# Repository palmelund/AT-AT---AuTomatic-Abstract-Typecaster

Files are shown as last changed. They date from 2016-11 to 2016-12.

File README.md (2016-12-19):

# AT-AT - AuTomatic Abstract Typecaster

The AT-AT is a sorting machine running on an embedded system and built in lego. The system combines a real-time system running on an Arduino Mega and Machine Intelligence running on an assisting computer.

The machine operates better under the tunes of the Imperial March.

## 5th semester project
This project was made as part of fifth semester of the bachelor in Software Engineering at Aalborg University where the project theme was Embedded software.

## Project structure
The project has the following overall structure to help organising files and source code.

* BmpSort
  * This is the computer side part of the project, that handles communication with the Kinect used as a camera, and makes shape recognition on the resulting image.
  * This part of the project is written in C#. Uses WPF for UI so a windows PC is needed right now.
* arduino
  * This is where all the source code for the Arduino is located, including libraries, API and the souce code
  * Written in C with a little bit of C++. Has full build script for Linux, but more manual work is needed if building on Windows.
* prototype
  * This is where the code for prototypes that was developed early in the project are located
  * This part is programmed in NXT-OSEK using C, LeJOS using Java and on the Arduino using C.
  * This code haven't been touched for a long time, and prototype 4 may not compile due to changes in the API.
* schematics
  * This is where schematics for the construction are located. There are currently two.
  * A wire schematic showing how the hardware is wired up. This can be opened using Fritzinf.
  * A digital model of the machine. This can be opened using LEGO Digital Designer.
  * A fault tree conducted from a fault tree analysis.
* test
  * This is where the code for unit testing, component testing and worst case execution time are located
  
## The Name
The machine was nameless for most of the project, but after every other student told us it looked like an AT-AT we finally gave in, named it AT-AT and printed a paper model of an AT-AT and taped onto it.
  
The name AuTomatic Abstract Typecaster was chosen because it represents what the project is:
* AuTomatic: The machine can operate on its own after it is started, only needing help to fill the feeder and empty the separation unit. These are both components that could also be automated away.
* Abstract: The machine itself can not be used in the industry, but it has many ideas that can be inherited and implemented by other machines to be used in practice.
* Typecaster: Since it is unknown what enters the machine, all is seen as objetcs. By passing though the machine it is being recognised and passed on as a shape, and in case of being a circle, it also has a color propery assigned to it.

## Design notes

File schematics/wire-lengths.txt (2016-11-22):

--- Red ---
++ 1  5v -> board+1                = red 12 cm
++ 6  board+1 -> board             = red 3 cm
++ 1  board+1 -> board+2           = red 8 cm
++ 1  board+2 -> ultra sound board = red 14 + 16 cm
++ 1  board+2 -> color sensor      = red 23 + 16 cm
TODO: Driver

--- Blue ---
++ 1  GND -> board-1               = blue 12 cm
++ 4  board-1 -> board             = blue 3 cm
++ 1  board-1 -> board-2           = blue 8 cm
++ 1  board-2 -> ultra sound board = blue 14 + 16 cm
++ 1  board-2 -> color sensor      = blue 23 + 16 cm
TODO: Driver

--- Yellow ---
++ 1  Pin 29 -> Transistor(Right)   = yellow 8 cm
++ 1  Pin 27 -> Transistor(Left)    = yellow 5 cm
++ 1  Pin 31 -> ultra sound board   = yellow 19 + 16 cm
TODO: Driver

--- Green ---
++ 1  Pin 53 -> ultra sound board   = green 19 + 16 cm
++ 1  Pin 51 -> Terminal(Left)      = green 10 cm

--- White ---
++ 1  Pin 3 -> Terminal(Left)       = white 11 cm
++ 1  Pin 2 -> Terminal(Middle)     = white 11 cm
++ 1  Pin 18 -> Terminal(Right)     = white 13 cm

--- Browm ---
++ 2 Pin 20/21 -> Color sensor      = brown 28 + 16 cm
TODO: Driver

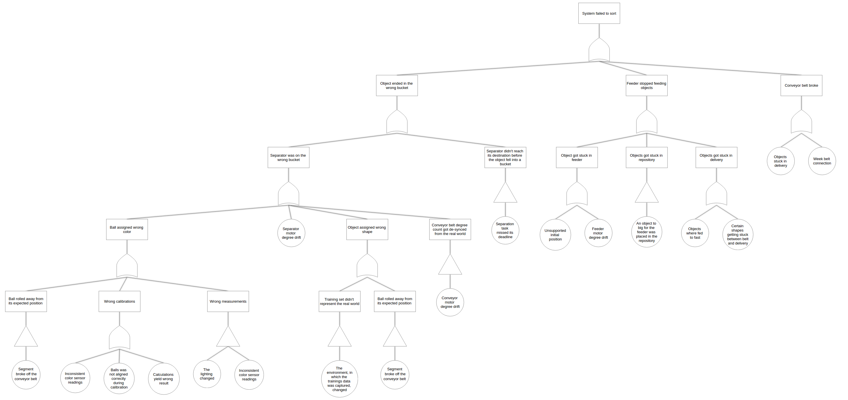
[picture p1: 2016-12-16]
schematics/FaultTreeV4.png

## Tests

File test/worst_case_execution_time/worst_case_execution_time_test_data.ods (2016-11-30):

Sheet: task_check_first_segment
0 | & | 952 | & | 20 | & | 928 | & | 40 | & | 932 | & | 60 | & | 928 | & | 80 | & | 928 | \\ | \hline
1 | & | 948 | & | 21 | & | 928 | & | 41 | & | 928 | & | 61 | & | 928 | & | 81 | & | 952 | \\ | \hline
2 | & | 936 | & | 22 | & | 948 | & | 42 | & | 904 | & | 62 | & | 932 | & | 82 | & | 952 | \\ | \hline
3 | & | 928 | & | 23 | & | 928 | & | 43 | & | 928 | & | 63 | & | 932 | & | 83 | & | 952 | \\ | \hline
4 | & | 956 | & | 24 | & | 932 | & | 44 | & | 928 | & | 64 | & | 928 | & | 84 | & | 952 | \\ | \hline
5 | & | 952 | & | 25 | & | 900 | & | 45 | & | 928 | & | 65 | & | 876 | & | 85 | & | 952 | \\ | \hline
6 | & | 928 | & | 26 | & | 928 | & | 46 | & | 900 | & | 66 | & | 852 | & | 86 | & | 928 | \\ | \hline
7 | & | 928 | & | 27 | & | 928 | & | 47 | & | 956 | & | 67 | & | 952 | & | 87 | & | 928 | \\ | \hline
8 | & | 904 | & | 28 | & | 936 | & | 48 | & | 956 | & | 68 | & | 952 | & | 88 | & | 932 | \\ | \hline
9 | & | 928 | & | 29 | & | 928 | & | 49 | & | 928 | & | 69 | & | 980 | & | 89 | & | 932 | \\ | \hline
10 | & | 928 | & | 30 | & | 952 | & | 50 | & | 928 | & | 70 | & | 952 | & | 90 | & | 952 | \\ | \hline
11 | & | 924 | & | 31 | & | 952 | & | 51 | & | 900 | & | 71 | & | 928 | & | 91 | & | 956 | \\ | \hline
12 | & | 928 | & | 32 | & | 932 | & | 52 | & | 900 | & | 72 | & | 876 | & | 92 | & | 928 | \\ | \hline
13 | & | 952 | & | 33 | & | 924 | & | 53 | & | 928 | & | 73 | & | 924 | & | 93 | & | 932 | \\ | \hline
14 | & | 932 | & | 34 | & | 904 | & | 54 | & | 928 | & | 74 | & | 952 | & | 94 | & | 928 | \\ | \hline
15 | & | 928 | & | 35 | & | 904 | & | 55 | & | 932 | & | 75 | & | 952 | & | 95 | & | 928 | \\ | \hline
16 | & | 932 | & | 36 | & | 928 | & | 56 | & | 948 | & | 76 | & | 928 | & | 96 | & | 932 | \\ | \hline
17 | & | 928 | & | 37 | & | 932 | & | 57 | & | 928 | & | 77 | & | 956 | & | 97 | & | 928 | \\ | \hline
18 | & | 928 | & | 38 | & | 932 | & | 58 | & | 948 | & | 78 | & | 928 | & | 98 | & | 928 | \\ | \hline
19 | & | 932 | & | 39 | & | 960 | & | 59 | & | 932 | & | 79 | & | 928 | & | 99 | & | 952 | \\ | \hline
0 | & | 952 | \\ | \hline
1 | & | 948 | \\ | \hline
2 | & | 936 | \\ | \hline
3 | & | 928 | \\ | \hline
4 | & | 956 | \\ | \hline
5 | & | 952 | \\ | \hline
6 | & | 928 | \\ | \hline
7 | & | 928 | \\ | \hline
8 | & | 904 | \\ | \hline
9 | & | 928 | \\ | \hline
10 | & | 928 | \\ | \hline
11 | & | 924 | \\ | \hline
12 | & | 928 | \\ | \hline
13 | & | 952 | \\ | \hline
14 | & | 932 | \\ | \hline
15 | & | 928 | \\ | \hline
16 | & | 932 | \\ | \hline
17 | & | 928 | \\ | \hline
18 | & | 928 | \\ | \hline
19 | & | 932 | \\ | \hline
20 | & | 928 | \\ | \hline
21 | & | 928 | \\ | \hline
22 | & | 948 | \\ | \hline
23 | & | 928 | \\ | \hline
24 | & | 932 | \\ | \hline
25 | & | 900 | \\ | \hline
26 | & | 928 | \\ | \hline
27 | & | 928 | \\ | \hline
28 | & | 936 | \\ | \hline
29 | & | 928 | \\ | \hline
30 | & | 952 | \\ | \hline
31 | & | 952 | \\ | \hline
32 | & | 932 | \\ | \hline
33 | & | 924 | \\ | \hline
34 | & | 904 | \\ | \hline
35 | & | 904 | \\ | \hline
36 | & | 928 | \\ | \hline
37 | & | 932 | \\ | \hline
38 | & | 932 | \\ | \hline
39 | & | 960 | \\ | \hline
40 | & | 932 | \\ | \hline
41 | & | 928 | \\ | \hline
42 | & | 904 | \\ | \hline
43 | & | 928 | \\ | \hline
44 | & | 928 | \\ | \hline
45 | & | 928 | \\ | \hline
46 | & | 900 | \\ | \hline
47 | & | 956 | \\ | \hline
48 | & | 956 | \\ | \hline
49 | & | 928 | \\ | \hline
50 | & | 928 | \\ | \hline
51 | & | 900 | \\ | \hline
52 | & | 900 | \\ | \hline
53 | & | 928 | \\ | \hline
54 | & | 928 | \\ | \hline
55 | & | 932 | \\ | \hline
56 | & | 948 | \\ | \hline
57 | & | 928 | \\ | \hline
58 | & | 948 | \\ | \hline
59 | & | 932 | \\ | \hline
60 | & | 928 | \\ | \hline
61 | & | 928 | \\ | \hline
62 | & | 932 | \\ | \hline
63 | & | 932 | \\ | \hline
64 | & | 928 | \\ | \hline
65 | & | 876 | \\ | \hline
66 | & | 852 | \\ | \hline
67 | & | 952 | \\ | \hline
68 | & | 952 | \\ | \hline
69 | & | 980 | \\ | \hline
70 | & | 952 | \\ | \hline
71 | & | 928 | \\ | \hline
72 | & | 876 | \\ | \hline
73 | & | 924 | \\ | \hline
74 | & | 952 | \\ | \hline
75 | & | 952 | \\ | \hline
76 | & | 928 | \\ | \hline
77 | & | 956 | \\ | \hline
78 | & | 928 | \\ | \hline
79 | & | 928 | \\ | \hline
80 | & | 928 | \\ | \hline
81 | & | 952 | \\ | \hline
82 | & | 952 | \\ | \hline
83 | & | 952 | \\ | \hline
84 | & | 952 | \\ | \hline
85 | & | 952 | \\ | \hline
86 | & | 928 | \\ | \hline
87 | & | 928 | \\ | \hline
88 | & | 932 | \\ | \hline
89 | & | 932 | \\ | \hline
90 | & | 952 | \\ | \hline
91 | & | 956 | \\ | \hline
92 | & | 928 | \\ | \hline
93 | & | 932 | \\ | \hline
94 | & | 928 | \\ | \hline
95 | & | 928 | \\ | \hline
96 | & | 932 | \\ | \hline
97 | & | 928 | \\ | \hline
98 | & | 928 | \\ | \hline
99 | & | 952 | \\ | \hline
 | Best | 852
 | Aveage | 931.92
 | Worst | 980

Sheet: task_send_take_picture
0 | & | 40 | & | 20 | & | 40 | & | 40 | & | 40 | & | 60 | & | 40 | & | 80 | & | 36 | \\ | \hline
1 | & | 40 | & | 21 | & | 40 | & | 41 | & | 40 | & | 61 | & | 40 | & | 81 | & | 36 | \\ | \hline
2 | & | 40 | & | 22 | & | 40 | & | 42 | & | 40 | & | 62 | & | 40 | & | 82 | & | 40 | \\ | \hline
3 | & | 40 | & | 23 | & | 40 | & | 43 | & | 48 | & | 63 | & | 40 | & | 83 | & | 36 | \\ | \hline
4 | & | 36 | & | 24 | & | 40 | & | 44 | & | 44 | & | 64 | & | 60 | & | 84 | & | 40 | \\ | \hline
5 | & | 40 | & | 25 | & | 40 | & | 45 | & | 40 | & | 65 | & | 40 | & | 85 | & | 40 | \\ | \hline
6 | & | 40 | & | 26 | & | 40 | & | 46 | & | 40 | & | 66 | & | 36 | & | 86 | & | 36 | \\ | \hline
7 | & | 36 | & | 27 | & | 36 | & | 47 | & | 36 | & | 67 | & | 40 | & | 87 | & | 40 | \\ | \hline
8 | & | 40 | & | 28 | & | 40 | & | 48 | & | 36 | & | 68 | & | 40 | & | 88 | & | 36 | \\ | \hline
9 | & | 40 | & | 29 | & | 40 | & | 49 | & | 40 | & | 69 | & | 44 | & | 89 | & | 40 | \\ | \hline
10 | & | 40 | & | 30 | & | 40 | & | 50 | & | 40 | & | 70 | & | 36 | & | 90 | & | 40 | \\ | \hline
11 | & | 40 | & | 31 | & | 40 | & | 51 | & | 40 | & | 71 | & | 40 | & | 91 | & | 36 | \\ | \hline
12 | & | 36 | & | 32 | & | 36 | & | 52 | & | 40 | & | 72 | & | 40 | & | 92 | & | 40 | \\ | \hline
13 | & | 36 | & | 33 | & | 40 | & | 53 | & | 40 | & | 73 | & | 36 | & | 93 | & | 40 | \\ | \hline
14 | & | 40 | & | 34 | & | 40 | & | 54 | & | 36 | & | 74 | & | 36 | & | 94 | & | 44 | \\ | \hline
15 | & | 40 | & | 35 | & | 40 | & | 55 | & | 40 | & | 75 | & | 40 | & | 95 | & | 40 | \\ | \hline
16 | & | 40 | & | 36 | & | 36 | & | 56 | & | 36 | & | 76 | & | 40 | & | 96 | & | 40 | \\ | \hline
17 | & | 40 | & | 37 | & | 40 | & | 57 | & | 40 | & | 77 | & | 36 | & | 97 | & | 36 | \\ | \hline
18 | & | 40 | & | 38 | & | 36 | & | 58 | & | 36 | & | 78 | & | 40 | & | 98 | & | 40 | \\ | \hline
19 | & | 44 | & | 39 | & | 36 | & | 59 | & | 36 | & | 79 | & | 40 | & | 99 | & | 40 | \\ | \hline
0 | & | 40 | \\ | \hline
1 | & | 40 | \\ | \hline
2 | & | 40 | \\ | \hline
3 | & | 40 | \\ | \hline
4 | & | 36 | \\ | \hline
5 | & | 40 | \\ | \hline
6 | & | 40 | \\ | \hline
7 | & | 36 | \\ | \hline
8 | & | 40 | \\ | \hline
9 | & | 40 | \\ | \hline
10 | & | 40 | \\ | \hline
11 | & | 40 | \\ | \hline
12 | & | 36 | \\ | \hline
13 | & | 36 | \\ | \hline
14 | & | 40 | \\ | \hline
15 | & | 40 | \\ | \hline
16 | & | 40 | \\ | \hline
17 | & | 40 | \\ | \hline
18 | & | 40 | \\ | \hline
19 | & | 44 | \\ | \hline
20 | & | 40 | \\ | \hline
21 | & | 40 | \\ | \hline
22 | & | 40 | \\ | \hline
23 | & | 40 | \\ | \hline
24 | & | 40 | \\ | \hline
25 | & | 40 | \\ | \hline
26 | & | 40 | \\ | \hline
27 | & | 36 | \\ | \hline
28 | & | 40 | \\ | \hline
29 | & | 40 | \\ | \hline
30 | & | 40 | \\ | \hline
31 | & | 40 | \\ | \hline
32 | & | 36 | \\ | \hline
33 | & | 40 | \\ | \hline
34 | & | 40 | \\ | \hline
35 | & | 40 | \\ | \hline
36 | & | 36 | \\ | \hline
37 | & | 40 | \\ | \hline
38 | & | 36 | \\ | \hline
39 | & | 36 | \\ | \hline
40 | & | 40 | \\ | \hline
41 | & | 40 | \\ | \hline
42 | & | 40 | \\ | \hline
43 | & | 48 | \\ | \hline
44 | & | 44 | \\ | \hline
45 | & | 40 | \\ | \hline
46 | & | 40 | \\ | \hline
47 | & | 36 | \\ | \hline
48 | & | 36 | \\ | \hline
49 | & | 40 | \\ | \hline
50 | & | 40 | \\ | \hline
51 | & | 40 | \\ | \hline
52 | & | 40 | \\ | \hline
53 | & | 40 | \\ | \hline
54 | & | 36 | \\ | \hline
55 | & | 40 | \\ | \hline
56 | & | 36 | \\ | \hline
57 | & | 40 | \\ | \hline
58 | & | 36 | \\ | \hline
59 | & | 36 | \\ | \hline
60 | & | 40 | \\ | \hline
61 | & | 40 | \\ | \hline
62 | & | 40 | \\ | \hline
63 | & | 40 | \\ | \hline
64 | & | 60 | \\ | \hline
65 | & | 40 | \\ | \hline
66 | & | 36 | \\ | \hline
67 | & | 40 | \\ | \hline
68 | & | 40 | \\ | \hline
69 | & | 44 | \\ | \hline
70 | & | 36 | \\ | \hline
71 | & | 40 | \\ | \hline
72 | & | 40 | \\ | \hline
73 | & | 36 | \\ | \hline
74 | & | 36 | \\ | \hline
75 | & | 40 | \\ | \hline
76 | & | 40 | \\ | \hline
77 | & | 36 | \\ | \hline
78 | & | 40 | \\ | \hline
79 | & | 40 | \\ | \hline
80 | & | 36 | \\ | \hline
81 | & | 36 | \\ | \hline
82 | & | 40 | \\ | \hline
83 | & | 36 | \\ | \hline
84 | & | 40 | \\ | \hline
85 | & | 40 | \\ | \hline
86 | & | 36 | \\ | \hline
87 | & | 40 | \\ | \hline
88 | & | 36 | \\ | \hline
89 | & | 40 | \\ | \hline
90 | & | 40 | \\ | \hline
91 | & | 36 | \\ | \hline
92 | & | 40 | \\ | \hline
93 | & | 40 | \\ | \hline
94 | & | 44 | \\ | \hline
95 | & | 40 | \\ | \hline
96 | & | 40 | \\ | \hline
97 | & | 36 | \\ | \hline
98 | & | 40 | \\ | \hline
99 | & | 40 | \\ | \hline
 | Best | 36
 | Aveage | 39.36
 | Worst | 60
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

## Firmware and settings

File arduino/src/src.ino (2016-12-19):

#include "src.h"

/* PLAN
 *
 * Startup command interface
 *  * Calibrate colors
 *  * Get color calibrations and measured distance
 *  * Start sorting machine
 *
 * Feed ball
 *  * feed_ball()
 * Ping color and Sound
 *  * Multiple code things
 * Send command
 *  * command_take_picture()
 * Request object
 *  * request_object_info()
 * Move separator
 *  * Multiple code things
 */

SFE_ISL29125 rgb_sensor;
Motor motor_conveyor, motor_feeder;
Advanced_Motor adv_motor_separator;

// 0: RED
// 1: GREEN
// 2: BLUE
// 3: YELLOW
// 4: BACKGROUND
Delta_RGB colors[COLOR_COUNT] = {
    {{941, 1147, 951}, 204},
    {{699, 1154, 978}, 225},
    {{698, 1122, 1134}, 234},
    {{1204, 1699, 1099}, 452}
    //{{708, 1087, 940}, 235}
};

Segment_Queue segment_queue;
int32_t conveyor_target;

// -------------------------------
// Arduino main functions
// -------------------------------
void setup()
{
    // Open serial connection
    Serial.begin(9600);
    while (!Serial)
        ;

    // Initialize color sensor
    rgb_sensor.init();

    DEBUG_PRINTLN("Initializing all components...");

    DEBUG_PRINTLN("- Motors...");
    
    motor_init(&motor_conveyor, 0.20, MOTOR_CONVEYOR_PIN, 
               MOTOR_CONVEYOR_INT_PIN, MOTOR_CONVEYOR_DATA_PIN,
               motor_conveyor_interrupt);
    motor_init(&motor_feeder, 1.0, MOTOR_FEEDER_PIN, 
               MOTOR_FEEDER_INT_PIN, MOTOR_FEEDER_DATA_PIN,
               motor_feeder_interrupt);

    advanced_motor_init(&adv_motor_separator, 1.0, MOTOR_SEPARATOR_PIN1,
                        MOTOR_SEPARATOR_PIN2, MOTOR_SEPARATOR_INT_PIN, MOTOR_SEPARATOR_DATA_PIN,
                        adv_motor_separator_interrupt1);

    DEBUG_PRINTLN("- Color sensor...");
    while (rgb_sensor.readRed() == 0 ||
           rgb_sensor.readGreen() == 0 ||
           rgb_sensor.readBlue() == 0)
        ;
    motor_stop(&motor_conveyor);

    for (;;)
    {
        Message message;
        io_await_message(&message);
        if (message.type == MESSAGE_TYPE_COMMAND &&
            message.command.type == MESSAGE_COMMAND_START)
        {
            break;
        }
    }

    motor_turn(&motor_conveyor);
    advanced_motor_turn_to_degree(&adv_motor_separator, GARBAGE_BUCKET);

#if CALIBRATE_COLORS
    task_calibrate_colors(&conveyor_target, &motor_conveyor, &rgb_sensor,
                          colors);
#endif
}

void loop()
{
    task_check_first_segment(&segment_queue);
    task_determin_color(&rgb_sensor, &segment_queue, colors);
    task_rotate_seperator(&adv_motor_separator, &segment_queue);
    task_feed_ball(&motor_feeder);

    if (motor_get_degrees(&motor_conveyor) >= conveyor_target)
    {
        // This will only happen if a deadline is missed
        ASSERT(false);
    }

    while (motor_get_degrees(&motor_conveyor) < conveyor_target)
    { }
    conveyor_target += SEGMENT_DEGREE_LENGTH;
}

// -------------------------------
// Interrupt functions
// -------------------------------
void motor_conveyor_interrupt()
{
    motor_update_degrees(&motor_conveyor);
}

void motor_feeder_interrupt()
{
    motor_update_degrees(&motor_feeder);
}

void adv_motor_separator_interrupt1()
{
    advanced_motor_update_degrees(&adv_motor_separator);
}

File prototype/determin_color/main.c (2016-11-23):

#include <stdio.h>

#define COLORS 8
typedef enum 
{
    RED     = 0,
    GREEN   = 1,
    BLUE    = 2,
    YELLOW  = 3,
    PINK    = 4,
    CYAN    = 5,
    WHITE   = 6,
    BLACK   = 7,
} Color;

short colors[COLORS][3]
{
    { 255,   0,   0 }, // RED
    {   0, 255,   0 }, // GREEN
    {   0,   0, 255 }, // BLUE
    { 255, 255,   0 }, // YELLOW
    { 255,   0, 255 }, // PINK
    {   0, 255, 255 }, // CYAN
    { 255, 255, 255 }, // WHITE
    {   0,   0,   0 }, // BLACK
};

#define ifprint(c, s) case c: printf(#s); break;

void print_color(Color color) 
{
    switch (color) {
        ifprint(RED,    Red);
        ifprint(GREEN,  Green);
        ifprint(BLUE,   Blue);
        ifprint(YELLOW, Yellow);
        ifprint(PINK,   Pink);
        ifprint(CYAN,   Cyan);
        ifprint(WHITE,  White);
        ifprint(BLACK,  Black);
    }
}

int isqrt(int number) 
{
    int res = 0;
    int bit = 1 << 30; // The second-to-top bit is set: 1 << 30 for 32 bits
 
    // "bit" starts at the highest power of four <= the argument.
    while (bit > number)
        bit >>= 2;
        
    while (bit != 0) 
    {
        if (number >= res + bit) 
        {
            number -= res + bit;
            res = (res >> 1) + bit;
        }
        else
        {
            res >>= 1;
        }

        bit >>= 2;
    }
    
    return res;
}

int euclidean_distanceance_3d(short* vec1, short* vec2) 
{
    int res1 = vec1[0] - vec2[0];
    int res2 = vec1[1] - vec2[1];
    int res3 = vec1[2] - vec2[2];

    return isqrt(res1*res1 + res2*res2 + res3*res3);
}

Color determin_color(short* rgb) 
{
    int i, min = 2147483647;
    Color res;

    for (i = 0; i < COLORS; i++) 
    {
        int distance = euclidean_distanceance_3d(colors[i], rgb);
        
        if (distance < min) {
            res = i;
            min = distance;
        }
    }

    return res;
}

#define determin_and_print(name, r, g, b)   \
short name[3] = { r, g, b };                \
printf(#name);                              \
printf(": ");                               \
print_color(determin_color(name));          \
printf("\n");                               

int main() 
{
    calibrate_sensor();
    determin_and_print(redish,    204,   0,   0 );
    determin_and_print(greenish,    0, 153,  51 );
    determin_and_print(blueish,     0,  51, 204 );
    determin_and_print(yellowish, 204, 204,   0 );
    determin_and_print(pinkish,   255,  77, 255 );
    determin_and_print(cyanish,     0, 255, 153 );
    determin_and_print(brownish,  102,  51,   0 );
    determin_and_print(darkgray,   64,  64,  64 );
    determin_and_print(lightgray, 191, 191, 191 );
    return 0;
}

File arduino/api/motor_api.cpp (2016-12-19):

#include "motor_api.h"

/************************
 * Non public functions *
 ************************/
int32_t base_motor_get_degrees(Base_Motor *motor)
{
    int32_t res;

    // Mark reading as true, so no race conditions occur
    motor->reading = true;
    res = motor->degrees;

    // Just to make sure motor->degrees never changes when reading = true
    ASSERT(res == motor->degrees);
    motor->reading = false;

    return res * motor->degree_ratio;
}

void base_motor_init(Base_Motor* motor, float degree_ratio,
                uint8_t interrupt_pin1, uint8_t interrupt_pin2, 
                void (*interrupt_handler)(void))
{
    motor->interrupt_pin1 = interrupt_pin1;
    motor->interrupt_pin2 = interrupt_pin2;
    motor->degree_ratio = degree_ratio;
    motor->buffer = 0;
    motor->degrees = 0;
    motor->reading = false;
    
    pinMode(interrupt_pin1, INPUT_PULLUP);
    pinMode(interrupt_pin2, INPUT_PULLUP);
    attachInterrupt(digitalPinToInterrupt(interrupt_pin1), 
                    interrupt_handler, CHANGE);
}



void base_motor_update_degrees(Base_Motor *motor)
{
    byte pattern = digitalRead(motor->interrupt_pin1);
    pattern |= (digitalRead(motor->interrupt_pin2) << 1);

    // We determin the direction by a pattern formed by the values
    // read from pin1 and pin2
    // LOW = 0, HIGH = 1
    switch (pattern)
    {
    case 0b11:
    case 0b00:
        motor->direction = FORWARD;
        break;
    case 0b10:
    case 0b01:
        motor->direction = BACKWARD;
        break;
    default:
        ASSERT(false);
        break;
    }

    // If degrees are being read, update a buffer instead to avoid race condtions
    if (motor->reading)
    {
        motor->buffer += motor->direction;
    }
    else
    {
        // We need to add and reset the buffer when we are allowed to
        // write to the degrees
        motor->degrees += motor->direction + motor->buffer;
        motor->buffer = 0;
    }
}

/********************
 * Public functions *
 ********************/
void motor_init(Motor *motor, float degree_ratio, uint8_t pin,
                uint8_t interrupt_pin1, uint8_t interrupt_pin2, 
                void (*interrupt_handler)(void))
{
    base_motor_init(&motor->base, degree_ratio, interrupt_pin1, 
                    interrupt_pin2, interrupt_handler);

    motor->pin = pin;
    pinMode(pin, OUTPUT);
}

void advanced_motor_init(Advanced_Motor *motor, float degree_ratio,
                         uint8_t pin1, uint8_t pin2, uint8_t interrupt_pin1,
                         uint8_t interrupt_pin2,
                         void (*interrupt_handler)(void))
{
    base_motor_init(&motor->base, degree_ratio, interrupt_pin1, 
                    interrupt_pin2, interrupt_handler);

    motor->pin1 = pin1;
    motor->pin2 = pin2;

    pinMode(pin1, OUTPUT);
    pinMode(pin2, OUTPUT);
}

bool advanced_motor_turn_to_degree(Advanced_Motor *motor, uint16_t degree)
{
    // Turn to degree should only accept a degree value between
    // 0 and 359 inclusive
    ASSERT(degree < 360);

    int32_t current_pos = advanced_motor_get_degrees(motor);

    // We need to floor, because default casting rounds towards 0, and
    // we always wants it to round down for these calculations to work.
    int32_t turns = floor(current_pos / 360.0);

    // We need to choose two goal, one above and one below our current_pos.
    // These goal needs to be the full number representaion of the degree number
    // that has to be reached.
    int32_t goal2, goal1 = 360 * turns + degree;
    int32_t distance_forward, distance_backward;

    if (goal1 > current_pos)
    {
        goal2 = 360 * (turns - 1) + degree;
        distance_forward = current_pos - goal2;
        distance_backward = goal1 - current_pos;
    }
    else if (goal1 < current_pos)
    {
        goal2 = 360 * (turns + 1) + degree;
        distance_forward = current_pos - goal1;
        distance_backward = goal2 - current_pos;
    }
    // If goal and current_pos are equal, the motor doesn't need to turn, so
    // we just return
    else
    {
        return;
    }

    ASSERT(distance_forward >= 0);
    ASSERT(distance_backward >= 0);

    // Choose which direction to turn based on which distance is shortest
    if (distance_forward < distance_backward)
        return advanced_motor_turn_degrees(motor, distance_forward, FORWARD);
    else
        return advanced_motor_turn_degrees(motor, distance_backward, BACKWARD);
}

bool motor_turn_to_degree(Motor *motor, uint16_t degree)
{
    // Turn to degree should only accept a degree value between
    // 0 and 359 inclusive
    ASSERT(degree < 360);

    int32_t current_pos = motor_get_degrees(motor);
    int32_t turns = (current_pos / 360);
    int32_t goal = 360 * turns + degree;

    // If goal is lower than current_pos, then we need to choose a new goal,
    // 360 degrees bigger
    if (goal < current_pos)
        goal = 360 * (turns + 1) + degree;

    // Turn motor by the distance to the goal
    return motor_turn_degrees(motor, goal - current_pos);
}

bool lesser_than(int32_t value1, int32_t value2)
{
    return value1 < value2;
}

bool greater_than(int32_t value1, int32_t value2)
{
    return value1 > value2;
}

bool advanced_motor_turn_degrees(Advanced_Motor *motor, uint16_t degrees,
                                 int8_t direction)
{
    // Calculate the goal that the motor should reach
    int32_t read_degrees = advanced_motor_get_degrees(motor);
    int32_t goal = read_degrees + ((int32_t)degrees * direction);
    bool (*compare_to)(int32_t, int32_t);

    advanced_motor_turn(motor, direction);

    // Wait for the motor to reach the goal
    switch (direction)
    {
    case FORWARD:
        compare_to = lesser_than;
        break;
    case BACKWARD:
        compare_to = greater_than;
        break;
    default:
        ASSERT(false);
        break;
    }

    int32_t previouse_read_degrees;
    uint32_t error_timeout = millis() + 500;

    bool retval = true;
    do
    {
        previouse_read_degrees = read_degrees;
        read_degrees = advanced_motor_get_degrees(motor);

        if (previouse_read_degrees != read_degrees)
            error_timeout = millis() + 500;
        else if (error_timeout < millis())
        {
            retval = false;
            break;
        }
    } while (compare_to(goal, read_degrees));

    advanced_motor_stop(motor);
    return retval;
}
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

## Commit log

2016-11-16 wireing schematics
    [p5-sorting-machine.fzz]
2016-11-16 Refactored the schematics for the sorting machine
    [p5-sorting-machine.fzz]
2016-11-16 More refactoring of schematics
    [p5-sorting-machine.fzz]
2016-11-17 Schematic done
    [p5-sorting-machine.fzz]
2016-11-18 Change interrupt wires to be white
    [p5-sorting-machine.fzz]
2016-11-18 Fixed wire colors on transistors
    [p5-sorting-machine.fzz]
2016-11-18 Wire lengths measured
    [p5-sorting-machine.fzz]
2016-11-22 sorter: removed button from source
2016-11-22 Made full version folder
    [p5-sorting-machine.fzz]
2016-11-22 Changes in defines to fit schematics
2016-11-22 removed arduino/sorting_machine and moved changes to arduino/src
2016-11-22 All defines changed to fit schematics
2016-11-23 arduino: io stuff + fix color related compile error
    [io_api.cpp, src.h, src.ino]
2016-11-23 Changes: - Moved c# projects that where irelevant to the projekt into the prototype folder - Work on io_api.cpp
2016-11-23 added c# library for arduino communcation * This should be merged into the existing solution instead
2016-11-24 color sensor calibration function implemented * To be tested
2016-11-24 Changes: - Tap indent changed from 2 to 4 in all files in the arduino folder - Implemented determin_color function - Changed some argument passing from by value to by reference
2016-11-25 work on communication + color sensor
2016-11-25 Color sensor works, we know how it works, but why it works correctly now
    [io_api.cpp, src.ino]
2016-11-25 arduino color is a strange place. Lets not go there
2016-11-25 Hopefully calibrate_color just works now, right?
2016-11-28 Fixed program not compiling
    [src.ino]
2016-11-28 started work on re-testing sound sensor
2016-11-28 work on machine, problems with degrees
    [motor_api.cpp, src.h, src.ino]
2016-11-28 Now uses arduino from PATH to compile
2016-11-28 can now upload to arduino by command line
2016-11-28 Kinda fixed motor interrupt... Kinda
    [motor_api.cpp, src.ino]
2016-11-29 Minor fixes and tests to the code
    [io_api.cpp, motor_api.cpp, src.h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]
2016-11-30 added spreadsheet with test data * The data can be copy pastaed into sharelatex after being formatted
    [worst_case_execution_time_test_data.ods]
2016-11-30 added more data to spreadsheet
    [worst_case_execution_time_test_data.ods]
2016-11-30 Lots of changes all around: - Changed the queue - Changed seperator task - Added new way to calibare colors - Minor changes all over
    "I only write good software" - Jimmi 2016
    [worst_case_execution_time_test_data.ods]
2016-12-01 Funktionalitet flttet til billeder der ligger i RAM
2016-12-02 Can now interact with the arduino through the computer interface. * Can now set the serial port at runtime to account for multiple computers with different setups. * Can send bytes to the Arduino (DO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
2016-12-02 added build script for windows * Still requires the program to be build from the Arduino IDE, but allows for the structure to remain split when working on it
2016-12-05 Fixed small bug in calibrate_color
2016-12-05 updates lego schematics
2016-12-05 added windows build script for component test * Building from the Arduino ide still required afterwards
2016-12-05 fixed color calibration, so we get better (correct) working data
2016-12-06 First (hopefully) running prototype
    everything is connected, model is 97,7% accurate
2016-12-06 added the motor part of the separator to the ldd model
2016-12-06 started working on the conveyor part of the ldd model
2016-12-07 small changes and fixes
    [tasks.cpp]
2016-12-07 minor fixes to bmp * Fixed exception thrown when closing the window without connecting the kinect. * Moved enums for SerialIO into its own files * Now closes connection to the Arduino on exit
2016-12-07 The sensors now ping more times for more precisions
2016-12-07 changes to arduino and bmp for debugging + work towards making the two work together
2016-12-08 Refactored the color calibrations into its own task
2016-12-08 Refactored calibrate_color in colors.cpp to determin_bounding_sphere
2016-12-08 Fixed the message implementation on SerialIO, so it matches up with the Arduino implementation. I don't know if this compiles though. Frederik plz help!
2016-12-08 Implemented the detection for motors not moving
2016-12-08 moved handling of motor error out into usercontrolled area
    [motor_api.cpp, tasks.cpp]
2016-12-09 bmp now sends response back to the arduino
2016-12-09 Change schematics and did some premature optimizations.
    [p5-sorting-machine.fzz]
2016-12-13 Refactored most of the userinterface. Now instead of a thread, images are taken on a BackgroundWorker. Other stuff was done to
2016-12-13 Fixed ImageProperties. It just works™
2016-12-13 Adjusted color calibration to give the best results for this project.
2016-12-13 Changes: - Added debug printing in user interface. - Changed all motors to use the same degree updater - Updated the worst case execution time testing - Other small things
2016-12-19 Pushed FaultTree. Final commit!!!
    [p5-sorting-machine.fzz]
